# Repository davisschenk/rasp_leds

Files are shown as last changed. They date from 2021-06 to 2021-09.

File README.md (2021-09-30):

# WS281x Raspberry PI Led Controller
This project was meant as a way for me to learn a little bit about electroics and pcb design, aswell as to be an outlet to learn rust and mess around with building a frontend for a larger project. This is very much still a WIP and I will be continuing to work on this project in my sparetime. I will do my best to document how things work and do small writeups explaining the project, if you are interested I highly encourage looking through the repository because I have readme's for each main section of this project (backend, frontend, hardware). Eventually I may document setup if anyone else is intrested in replicating this, but for now im still working on improving pretty much everything.

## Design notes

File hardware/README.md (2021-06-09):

# Hardware
I used a Raspberry PI 3 B+ with a custom PCB mounted on top that handles signal level conversion and the connection with the leds through a custom made wire. Below is a parts list with everything I used, and all the files for the custom pcb I designed using kicad are also in this directory. I chose to switch to using a 4 pin connector in case I ever decide that I would like to use WS2815 leds instead of W2812b due to the fact that the WS2812b's suffer from lots of voltage drop.

## Parts used
* Raspberry PI 3 B+
* 3.3v -> 5v Logic Level Converter ([BOB-12009](https://www.digikey.com/en/products/detail/sparkfun-electronics/BOB-12009/5673795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))
* WS2812b LED light strip
* [5v Barrel Powerjack](https://www.digikey.com/en/products/detail/cui-devices/PJ-063AH/2161208)
* Micro-Fit 3.0 Molex Connectors
    * [Header connector](https://www.digikey.com/en/products/detail/molex/0430450400/252527?s=N4IgTCBcDaIOoFkCMAOJAWAtAOQCIgF0BfIA)
    * [Cable Assembly](https://www.digikey.com/en/products/detail/molex/0451320401/6208003?s=N4IgTCBcDaIAQMQg6gWQIwDZ1YLQDkAREAXQF8g)
* 03/18 Solid Core Thermostat Cable
* 5v power supply
* [Custom designed pcb](raspberrypi-led-hat)

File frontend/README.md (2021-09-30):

# Frontend
I initially tried to build the frontend using ReactJS, but eventually moved to flutter because I was having a hard time relearning web design with JS/HTML/CSS, and I also just do not enjoy interacting with JS. Fortunately for me I have some previous experience developing with flutter, and it will also allow me to easily build my frontend for web, android, ios, etc with minimal effort. Currently I am just using the most basic option for state management (`setState({})`) because currently there isnt very much complex state, eventually I may opt to upgrade to another solution, but currently it works good enough. UI design is not my strong suit, but hopefully I will have this looking nice and clean eventually but for now im focused on just getting something working.

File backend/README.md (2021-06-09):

# Rust Backend
The backend is a rocket server which serves the frontend, manages a json api and runs a thread which is used to control the led strips.

The thread which runs the led strips is a state machine which receives JSON messages over channels from the main thread which control state transition. Below is a diagram which shows how this state machine works.



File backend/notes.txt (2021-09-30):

{
  "type": "pattern",
  "data": {
    "pattern": "moving_dot",
    "tick_rate": 10,
    "tick_cycle": 300,
    "color": [0, 255, 0, 0]
  }
}

{
  "type": "pattern",
  "data": {
    "pattern": "strobe",
    "tick_rate": 10,
    "color": [0, 255, 0, 0]
  }
}

{
  "type": "pattern",
  "data": {
    "pattern": "solid",
    "color": [0, 255, 0, 0]
  }
}

{
  "type": "pattern",
  "data": {
    "pattern": "random",
    "tick_rate": 100
  }
}

{
  "type": "idle",
  "data": {
  	"clear": true
  }
}

{
  "type": "power",
  "data": {
  	"mode": "On"
  }
}

{
  "type": "pattern",
  "data": {
    "pattern": "meteor",
    "tick_rate": 100,
    "color": [255, 0, 255, 0],
    "random_decay": true,
    "decay": 128,
    "size": 16
  }
}

{
  "type": "pattern",
  "data": {
    "pattern": "rainbow_cycle",
    "tick_rate": 100
  }
}

{
  "type": "pattern",
  "data": {
    "pattern": "timer",
    "tick_rate": 100,
    "color": [255,0,0,0],
    "timestamp": "2021-05-26 18:30:00"
  }
}

{
  "type": "pattern",
  "data": {
    "pattern": "alternating",
    "colors": [
      {
      	"count": 2,
        "color": [255, 255, 0, 0]
      },
      {
      	"count": 3,
        "color": [255, 0, 255, 0]
      },
      {
      	"count": 2,
        "color": [0, 255, 255, 0]
      } 
     ]
  }
}

{
  "type": "pattern",
  "data": {
    "pattern": "rotate",
    "tick_rate": 1000,
    "direction": "counter"
  }
}

Color Order: BGRA

Runner State Machine

Idle -> wait for message with blocking
Pattern -> {
    call start_tick on pattern
    increment tick
    check for message no blocking {

    }
}

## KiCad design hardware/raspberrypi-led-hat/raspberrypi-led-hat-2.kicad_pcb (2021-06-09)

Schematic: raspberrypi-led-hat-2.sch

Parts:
J1: Barrel_Jack; BarrelJack_CUI_PJ-063AH_Horizontal
J2: Conn_02x02_Counter_Clockwise; 430450400
MK1, MK2, MK3, MK4: M2.5; MountingHole_2.7mm_M2.5
P1: Conn_02x20_Odd_Even; PinSocket_2x20_P2.54mm_Vertical
R1: R; R_Axial_DIN0204_L3.6mm_D1.6mm_P2.54mm_Vertical
SW1: SW_Push; SW_PUSH_6mm
U1: BOB-12009; CONV_BOB-12009; PARTREV 01

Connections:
+3V3: P1.1, P1.17, SW1.1, U1.LV
+5V: J1.1, J2.1, U1.HV
/GPIO2(SDA1): P1.3
/GPIO3(SCL1): P1.5
/GPIO4(GCLK): P1.7
/GPIO5: P1.29
/GPIO6: P1.31
/GPIO7(SPI1_CE_N): P1.26
/GPIO8(SPI0_CE_N): P1.24
/GPIO9(SPI0_MISO): P1.21
/GPIO10(SPI0_MOSI): P1.19
/GPIO11(SPI0_SCK): P1.23
/GPIO12(PWM0): P1.32
/GPIO13(PWM1): P1.33
/GPIO14(TXD0): P1.8
/GPIO15(RXD0): P1.10, R1.2
/GPIO16: P1.36
/GPIO17(GEN0): P1.11
/GPIO18(GEN1)(PWM0): P1.12, U1.LV1
/GPIO19(SPI1_MISO): P1.35
/GPIO20(SPI1_MOSI): P1.38
/GPIO21(SPI1_SCK): P1.40
/GPIO22(GEN3): P1.15
/GPIO23(GEN4): P1.16
/GPIO24(GEN5): P1.18
/GPIO25(GEN6): P1.22
/GPIO26: P1.37
/GPIO27(GEN2): P1.13
/ID_SC: P1.28
/ID_SD: P1.27
/LED_DATA: J2.3, J2.4, U1.HV1
GND: J1.2, J2.2, P1.6, P1.9, P1.14, P1.20, P1.25, P1.30, P1.34, P1.39, U1.GND_1 (GND), U1.GND_2 (GND)
unnamed: P1.2, P1.4
unnamed: R1.1, SW1.2

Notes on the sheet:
ID_SD and ID_SC PINS: These pins are reserved for HAT ID EEPROM. At boot time this I2C interface will be interrogated to look for an EEPROM that identifes the attached board and allows automagic setup of the GPIOs (and optionally, Linux drivers). DO NOT USE these pins for anything other than attach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
Mounting Holes

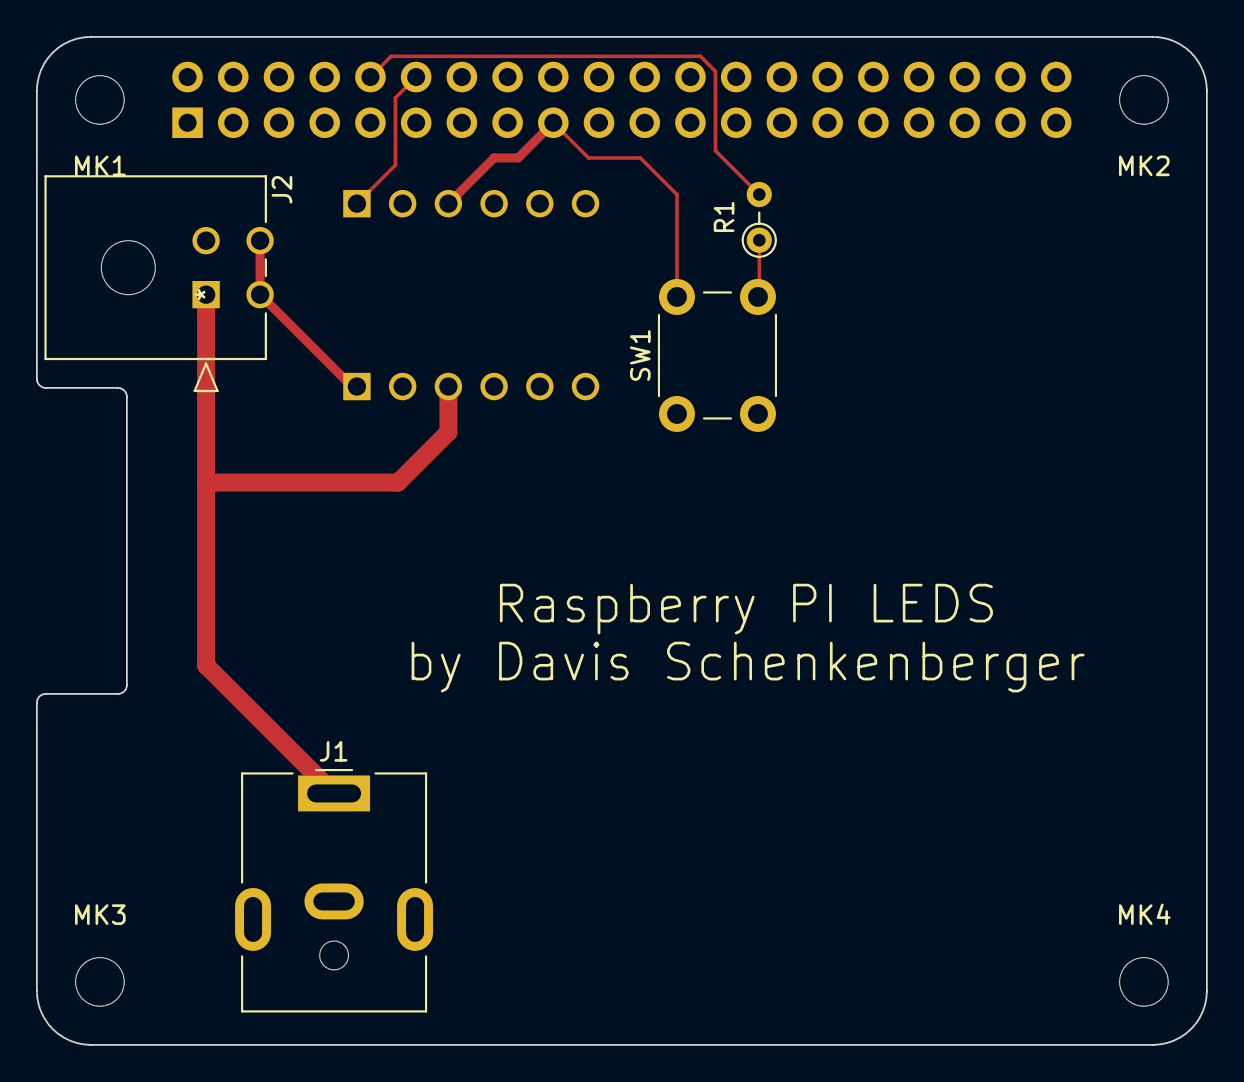
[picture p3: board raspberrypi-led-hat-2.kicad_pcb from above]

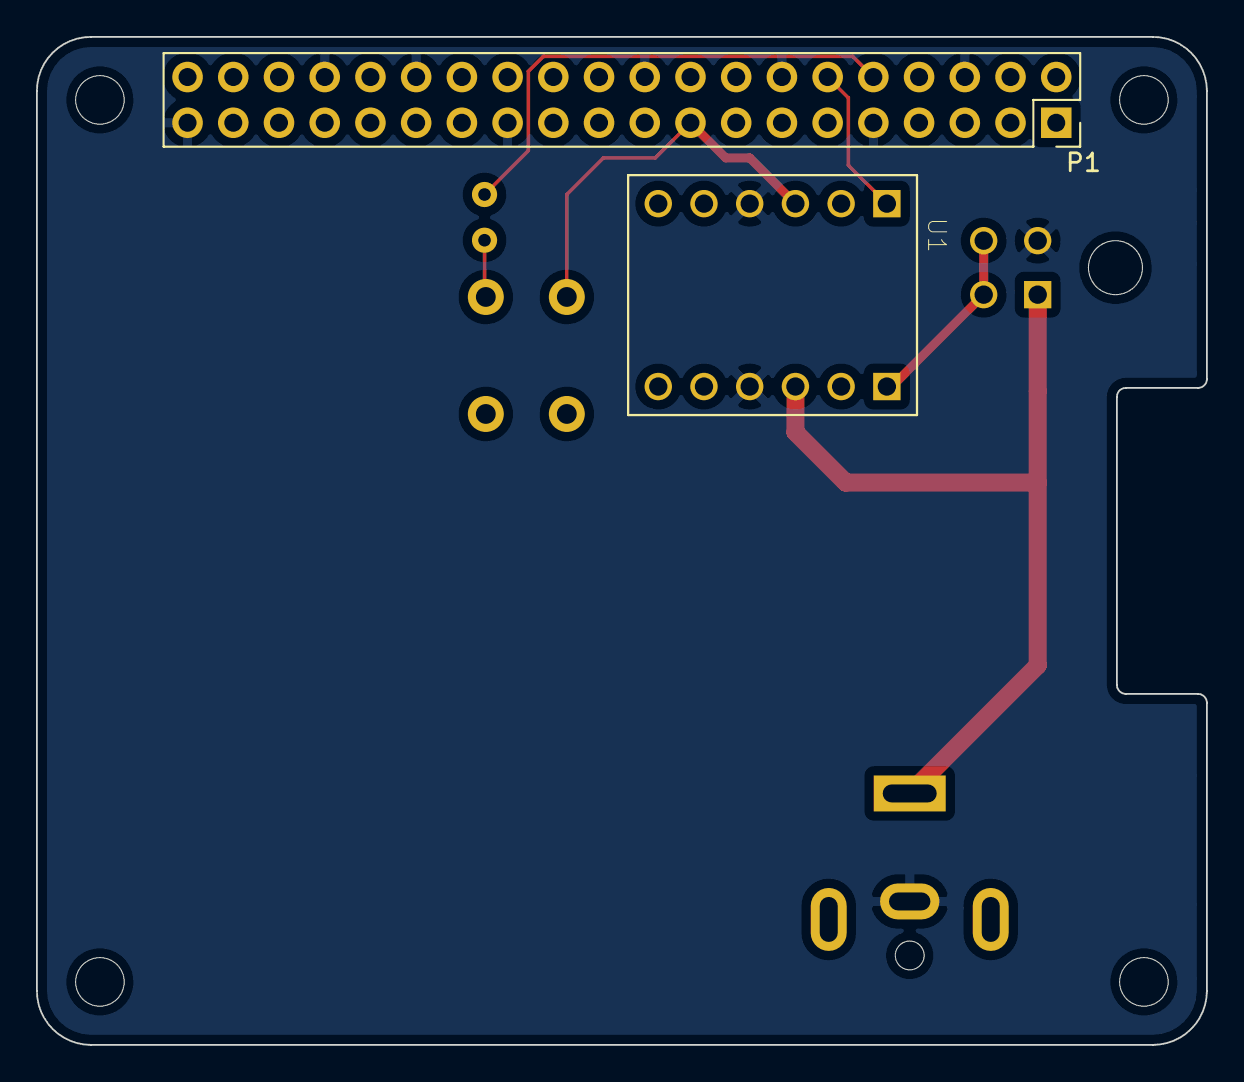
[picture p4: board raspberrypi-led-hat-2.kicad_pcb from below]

Board: 2 copper layers, 65.0 x 56.0 mm, 10 parts (2 on the bottom side), 8 nets.

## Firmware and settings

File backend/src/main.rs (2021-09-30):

#![feature(proc_macro_hygiene, decl_macro)]
#[macro_use]
extern crate rocket;
mod led_driver;
mod patterns;

use rocket::Data;
use rocket::State;
use rocket_contrib::serve::StaticFiles;
use std::io::Read;
use std::sync::{Arc, Mutex};

type StateRunner<'a> = State<'a, Arc<Mutex<led_driver::Runner>>>;

const PIN: i32 = 18;
const COUNT: i32 = 300;
const BRIGHTNESS: u8 = 128;

#[post("/pattern", data = "<data>")]
fn pattern(data: Data, runner: StateRunner) -> led_driver::LedResponse {
    let mut buffer = String::new();
    data.open().read_to_string(&mut buffer).unwrap();

    let locked = runner.lock().unwrap();
    (*locked).send(buffer)
}

fn main() {
    let mut runner = led_driver::Runner::new(PIN, COUNT, BRIGHTNESS);
    runner.start();

    let managed_runner = Arc::new(Mutex::new(runner));

    rocket::ignite()
        .manage(managed_runner)
        .mount("/", StaticFiles::from("/home/pi/rasp_leds/web"))
        .mount("/api", routes![pattern])
        .launch();
}

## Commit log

2021-06-07 Added schematic for LED Raspberry PI hat
    [raspberrypi-led-hat.kicad_pcb, raspberrypi-led-hat.sch]
2021-06-07 Added more files for schematic
2021-06-09 Remade hat kicad and added readme
    [raspberrypi-led-hat-2-B_CrtYd.gbr, raspberrypi-led-hat-2-B_Cu.gbl, raspberrypi-led-hat-2-B_Mask.gbs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]
2021-06-12 Added RenderOnce tick action to avoid boiler plate in static patterns
2021-06-16 Switched from react to flutter
2021-09-30 added pattern and power mode

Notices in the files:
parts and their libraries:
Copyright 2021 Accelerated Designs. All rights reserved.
